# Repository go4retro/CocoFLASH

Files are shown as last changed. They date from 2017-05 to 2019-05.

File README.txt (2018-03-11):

TANDY Color Computer/Dragon FLASH ROM Cartridge

Copyright (C) 2016-18  Jim Brain, RETRO Innovations

These files are free designs; you can redistribute them and/or modify
them under the terms of the Creative Commons Attribution-ShareAlike 
4.0 International License.

You should have received a copy of the license along with this
work. If not, see <http://creativecommons.org/licenses/by-sa/4.0/>.

These files are distributed in the hope that they will be useful,
but WITHOUT ANY WARRANTY; without even the implied warranty of
MERCHANTABILITY or FITNESS FOR A PARTICULAR PURPOSE.  See the
license for more details.

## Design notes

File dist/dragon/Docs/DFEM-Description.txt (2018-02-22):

DFEM14U DESCRIPTION
===================
I have written a program to be able to use the CoCo-Flash module 
designed and built by Retroinnovations (Jim Brain) that contains 
8 Mytes of FLASH memory, 64k of SPI EEPROM and as a bonus it has a 
full compatible Orchestra 90CC double DAC incorporated.
The flash is maped to $c000-$feff (16k-256 bytes) so it can contain 
any Dragon-CoCo2 ROM we have. Moving that 'visible' window along the
FLASH contents we can store/read biggger programs (BIN or BAS files)
You will find info about that module here:
http://www.go4retro.com/products/cocoflash/

'DFEM' stands for "Dragon Flash Eeprom Manager"
The program will 'flash' programs in chunks of 16k, from $3000-6fff 
and later you could start them from the program list.
I decided to allow Binary and Basic programs besides the normal ROMs, 
so I added some code to copy those programs to RAM and execute/run them.
These loaders are part of the Program Manager, so there is no need to
add them at the beginning of the programs we want to store in Flash.

To make it easy for the user, the module should contain a customized version 
of my DosPlus5.0 extended (DP50E from now on) on bank zero. We will flash
it here if it isn't yet there.
This DP50E will copy some code into RAM and start it. The copied code will 
switch the bank on the flash module so that it can copy the Program Manager 
and in turn, start it.
The only thing that the user has to do is press the module button that 
prevents the ROM from autostarting. The DOS must be called by the Basic
after it has initialized the Dragon. If you don't press that button, the 
Dragon will simply hang :-(

I have used the SPI EEPROM included in the module as a database where the 
relevant data for each program is stored. The idea was given to me by Jim Brain. 
The programs are always shown in alpha order. Basically the EEPROM contains 
records that point to the next one, so it is a simple linked list.

To get an idea about the capacity of that module, let's  assume that all
programs (Binaries/Basic/Rom) will have a mean length of 16k, then as it
has 8 Mbytes, we could add (8Mb/16k) -> 500 programs, but if they are smaller
then we could add a lot more. 
The limit imposed by the EEPROM database is 1600 entries, so it seems that
we will not have problems for that reason.

I have created two tables in the EEPROM to help work with these entries
- One that contains 26 Categories that can be assigned to the programs
- Another for HotKeys that admits 26 entries too.
The Category can be shared by many programs, but the HotKey will point to 
only one program.

How to configure the Flash module to work on the Dragon
=======================================================
Most probably the flash will arrive to you with software for the CoCo, so we need to erase it.
The procedure we shoud apply, using some tools I included in the pack, is this
1) We CLOADM"FERASALL.WAV" or DWLOAD"FERASALL.BIN", it will ask you for the slot number where 
   the Flash module is, you can answer 0 (for no MPI) or 1-2-3-4
   Once selected, the chip will be fully erased. Don't worry if it lasts some time. The program
   sends only one command to the chip but it takes long to do the task.
2) We need to flash the Program Manager, I call it DFEM (Dragon Flash Eeprom Manager), we will
   use CLOADM"F16KFM.WAV" or DWLOAD"F16KFM.BIN", again it will ask where the module is.
3) Finally we will flash a customized version of the DP50E that will start the DFEM, for this step 
   we CLOADM"F16KDP.WAV" or DWLOAD"F16KDP.BIN"

From this moment, we may start/restart the Dragon/Tano while pressing the button on the flash module.
The Basic will call the DP50E and this will exec the DFEM so the main menu will be displayed.
On entering the program, it verifies if the EEPROM database exists, and if it is not yet created,
it will create/format the EEPROM as needed.

Possible Hardware Setups
========================
Apart from our Dragon and the Flash Module, we need some way to access/load program files to RAM
from some external hardware in oder to flash them into the module with the DFEM

These are the choices I have tested
-  A drivewire serial to USB converter, conected to a PC/Mac where we are runnuing a Drivewire server 
   (or any small Arduino/R-Pi that does the same). This is my preferred setup!
   By the way, here you can see one adapter for that setup
   http://tormod.me/products.html

-  A Tandy Multi-Pack (MPI) or a mini-MPI, together with a CoCo-SDC
   This one has the advantage of enabling us to use the Orchestra 90CC from the flash module and 
   access the score-disks from the CoCo-SDC, despite the procedure is a bit tricky. 
   I explain it at the end of this document 

Someone could also try to replace the CoCo-SDC in this last setup with a drive controller
but this has not been tested by me.

Pack Contents
=============
In the attached zip you should find:

DFEM14U.VDK that contains some utilities for the real CoCo-Flash module and a Test version
of the program. This is only of use if you have Drivewire ot the MPI and the CoCo-SDC.

All of the binary files are included as individual files in BIN format for DW use
and in WAV format for tape/Audacity use
The programs/utilities are:
DFEM14UT - The Test Version of the Program (works fine on XRoar and on any Dragon)
F16KDP   - Flashes into module the customized version of DP50E
F16KFM   - Flashes into module the Flasher Manager Program (DFEM)
EREADTAB - Shows structured Eeprom contents: LowReg, Records and Tables
FERASALL - Erases the whole FLASH chip (8Mbytes)
FERASEC  - Erases one FLASH sector (value needs to be POKED $4007-4008)
FREADALL - Shows Flashed data (shows 128 of every 256 bytes sector)
SWMAP1   - This program copies ROM to RAM and stays in MAP1 (all RAM)
TEST     - a bas file to start the Test version (ONLY in the VDK)

And two Java utility programs
Addresses  this one will create an output text file with the addresses of all the programs
           (binary or Basic) that are in the folder selected by the user. Loops untill you
           press on Cancel (to allow for another subdirectory)
MakeROM	   Selecting a folder with some programs, will create the ROM chunks needed (1 or 2)
	   will add -R1, -R2 to these parts.

FOR TEST VERSION ONLY
=====================
You can practice with the Test version, it has space reserved for *ONLY* 32 entries.
On XRoar or on a SDC you can run the program TEST.BAS to strat it
On Drivewire you simply DWLOAD"DFEM14UT.BIN"

You should know that the info you'll enter will *NOT* be saved on exit, it is just for 
practicing purposes! It simply 'emulates' the EEPROM into RAM, not the FLASH of course.
Anyway, if you want to keep the entered data to use it later, then you could do this
- Exit the program pressing the '3' key on the main menu 
- SAVE"MYDATA",&H2ea8,&H36e2,&H2ea8 or alternatively CSAVEM"MYDATA",&H2ea8,&H36e2,&H2ea8
- Later, to re-use it after starting the TEST program, just press '3' to Quit and
  LOAD"MYDATA"  or CLOADM"MYDATA"
- EXEC&H1400 and you will work with your last saved data
To be able to save to disk (VDK files), you will need to access a drivewire server
and use the DP50E functions to mount the desired disk
*** DO NOT USE THESE TRICK WITH THE REAL VERSION, IT USES THE EEPROM INSTEAD ***

HOW TO PLAY ORCHESTRA 90CC SCORES FROM THE COCO-SDC
===================================================
- Set the MPI to the slot where the Flash is
- Start the Dragon/Tano while pressing the button on the module
- Exit the program with '3'
- DWLOAD"SWMAP1.BIN" so that the DP50E gets copied into RAM
- SDRIVE1,"MUSICA" ... assuming that MUSICA is a folder where we have 10 VDK
  with ORC90 scores. This changes to slot# where the SDC is
  If you don't remember, you can use SDIR to find it out
- SLOTN4 to set the MPI switch back to slot#4 in my case. Use the number
  1-2-3-4 where you have the Flash module
- POKE&HFFDE,0 to switch to MAP0 because programs reside in ROM (Flash)
- EXEC&H1400 to enter the DFEM
- '1' to go to Program Management
- Search for the Orchestra90cc and press 'S' to start it
- Shift-Enter (recommended to be able to play at double speed)
- Now we need to change 'internally' to the slot where the SDC is
  in my case is slot #1, so I enter command '0' and enter in Orchestra
  The change slot commands are 0-1-2-3 (pressing H will show help screen)
- Now you can work with Orchestra using the contents of the selected disk
  in drive 1. Remember that pressing the button on the SDC changes to the 
  next numbered disk in that folder (only drive 1)
  As I want to listen to all of the scores I do enter
- Y * (and shift enter)
You can connect the stereo audio jack output on the Flash module to any 
amplifier to listen to the music. Enjoy!

Epilogue
========
Well, now we can say ....
Another CoCo add-on that can be used on our Dragon/Tano
I hope you enjoy your Coco-Flash module!

cheers
pere

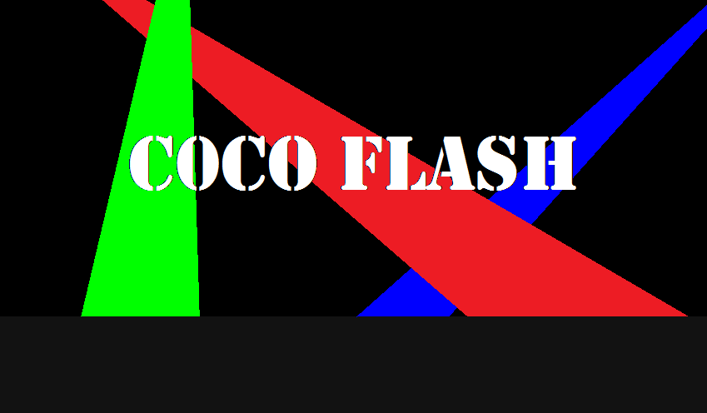
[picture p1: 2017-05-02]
doc/Coco Flash Cartridge Label.png

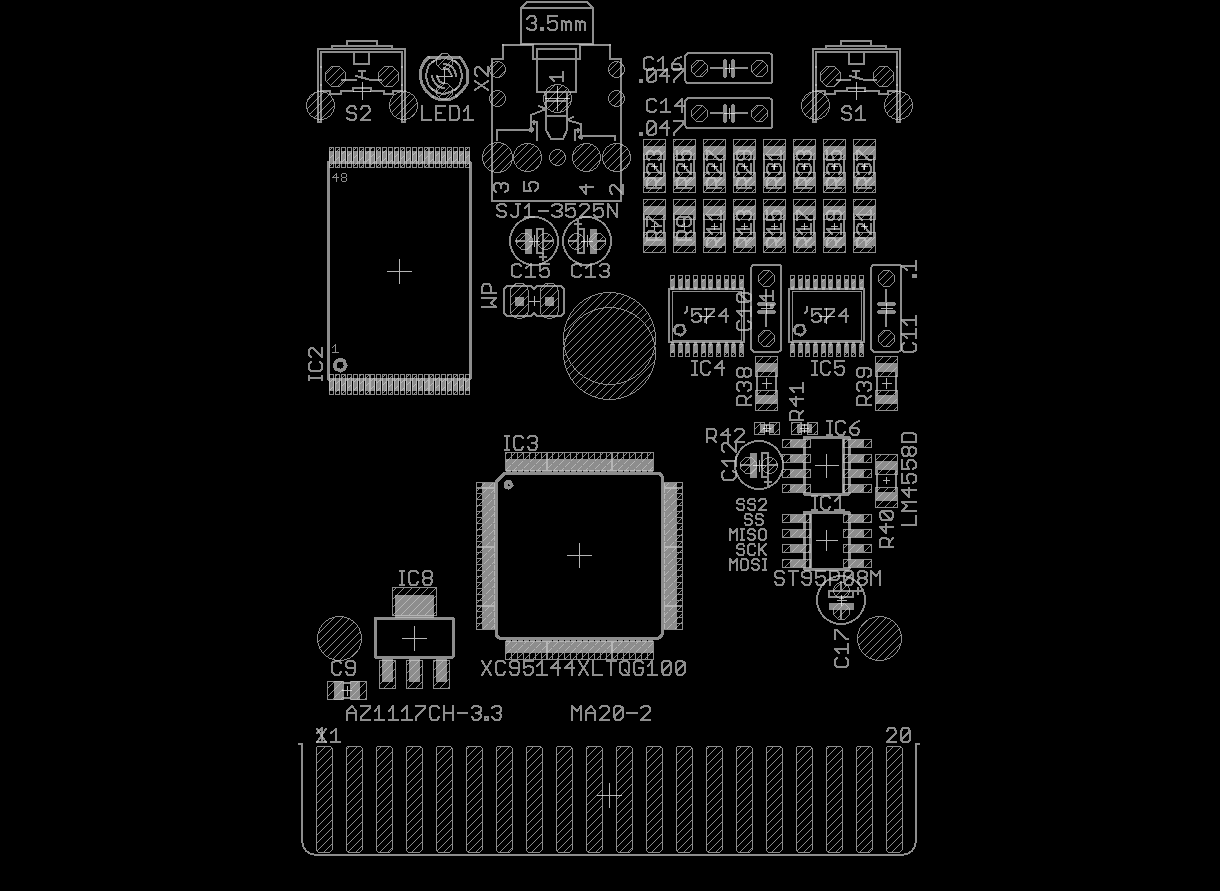
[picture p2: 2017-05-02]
pcb/tplace.png

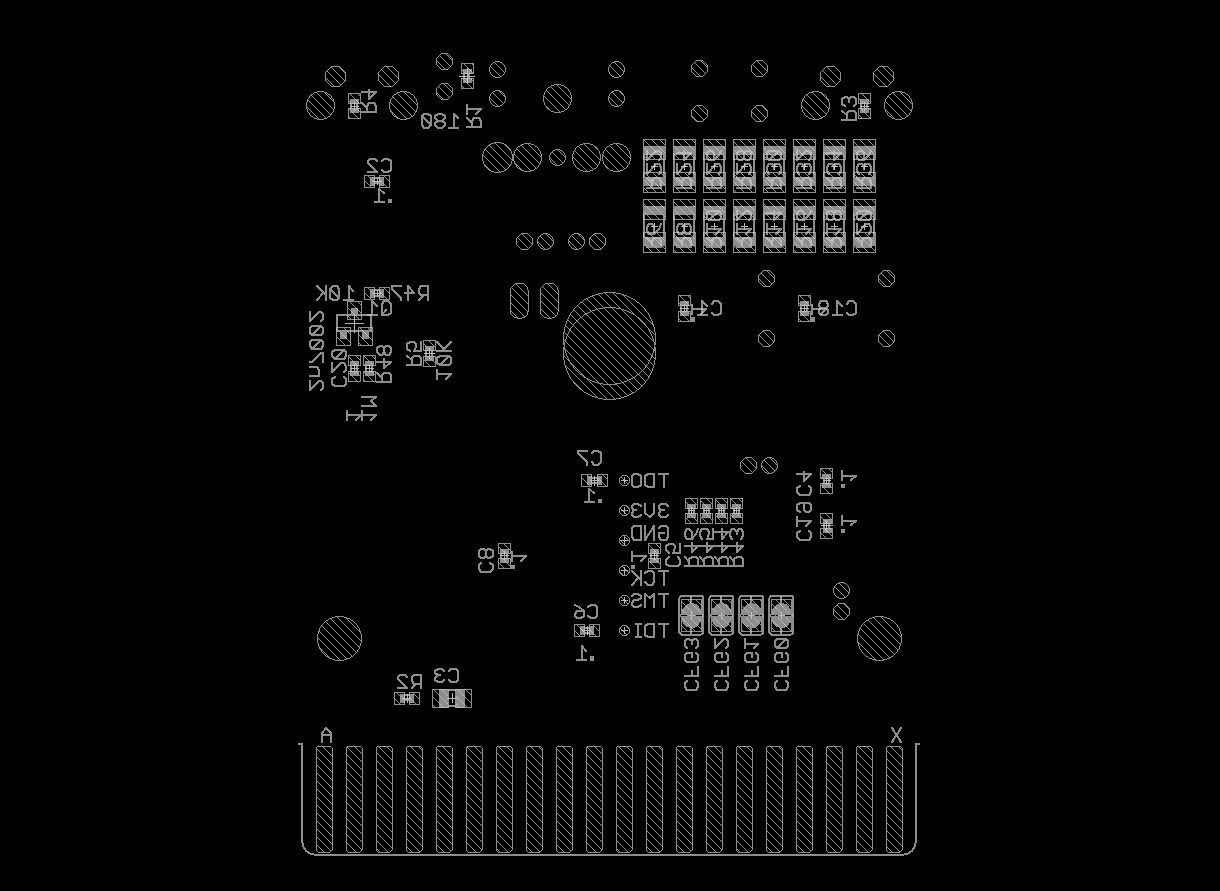
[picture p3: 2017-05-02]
pcb/bplace.png

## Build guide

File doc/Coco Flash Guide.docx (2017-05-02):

Retro Innovations

Coco Flash User Guide

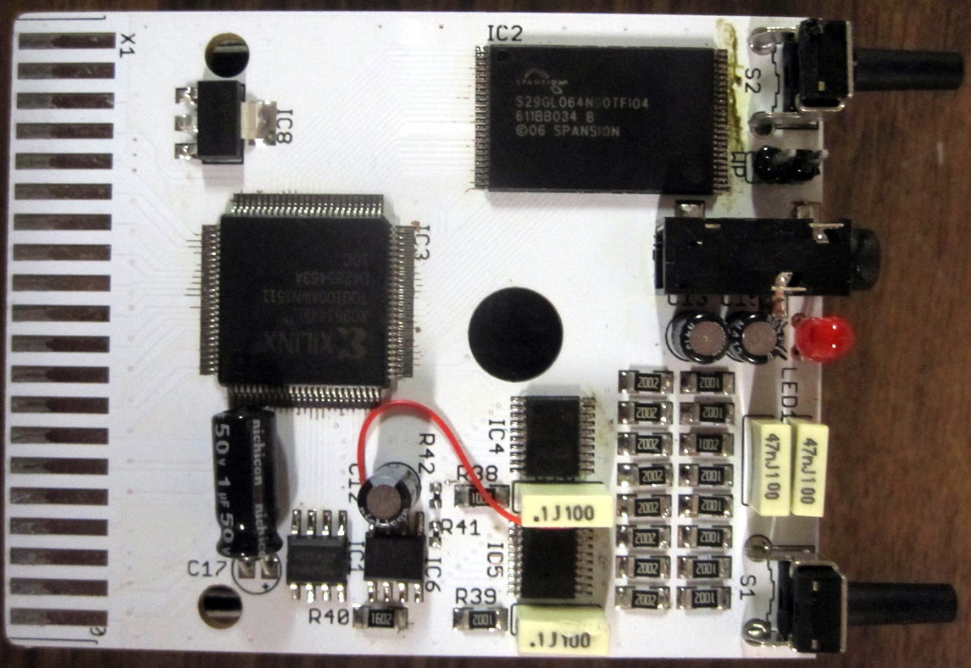
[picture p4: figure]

Retro Innovations

# CoCo Flash User Guide

Table of Contents

Description of the CoCo Flash Cartridge

This section describes what the capabilities of the CoCo Flash are and how it can be used.

t

he CoCo Flash is a programmable flash ROM cartridge. This cartridge can be used to store multiple game and DOS cartridge ROMs which can then be selected from the menu to be used. The Coco Flash can contain up to 2,048 4k ROMs at once. The sizes of these ROMs can range from 2k to 256k. Banked ROMs larger than 32k games such as Robo Cop and Predator are supported. 32k ROMs are capable of being installed by either banking or the CoCo 3 only method of mapping a full 32k ROM. The CoCo Flash is capable of being used as an Orchestra90 sound cartridge and is fully compatible with the original Orchestra 90 Cartridge, which was manufactured by Radio Shack. The CoCo Flash includes a user customizable menu which is written in BASIC. This allows the menu to be edited to list your own choice of ROMs. The CoCo Flash is also pre-loaded with 5 ROMs. The Coco Flash has a copy of HDBDOS, which is configured to auto detect a CoCo 1/2 or CoCo 3 and is configured to use a DriveWire server. The Orchestra 90 ROM is pre-loaded into the CoCo Flash as well. The CoCo Flash also contains the games “Doodle Bug”, “Buzzard Bait”, and “Temple of ROM”.

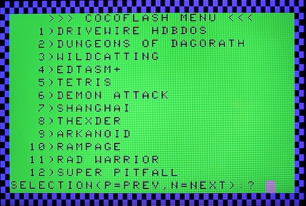
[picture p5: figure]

# How to Customize The CoCo Flash Menu

The CoCo Flash Menu is written in basic. The menu is customizable to users by loading the menu through the command:

LOAD "MENU.BAS"

After you have done this you can edit data statements from lines 10000 - 10998 to add your program info into the menu. The info you add for your program will be in this format:

"NAME OF PROGRAM",bank#,type#

- NAME OF PROGRAM represents the title or name of the added program as it will appear on the menu screen.
- bank# represents the first bank number used for the program you are adding. If you are adding a 32k program the number should be the first bank being used in the second chunk of 16k.
- type# represents the type of program you are adding. The three common options that can be used are 2, 0, and 34. The number 2 means that a game program which uses the IRQ to start is being added to the menu. If 0 has been entered then a DOS program has most likely been added. DOS programs have DK in the first two bytes of the ROM image. When the color computer starts it checks the cartridge rom memory location to see if the first two characters are DK and if they are it launches the contents of the cartridge as a basic DOS extension which adds commands to basic. Lastly, if the value is 34 then the cartridge has been split into multiple 16k cartridges. In other words, programs that are 128k, 64k, or some 32k cartridges use the 34 value since the largest CoCo ROM bank on a CoCo 1 or 2 that can be used is 16k at a time.

Once you have finished adding the entry to the menu, save the program using the command:

SAVE "MENU.BAS"

Now, because this is a basic program and ROMs only allow machine code programs to be stored in them, you must convert the basic program to machine code. Fortunately, the menu program has a routine built into it to do this. To convert the menu to machine code use the command:

RUN 60000

This will create a file named “BASROM.BIN” that can be programmed into bank 0 of the CoCo Flash. Please note that banks 0 and 1 are both reserved for the menu. The next section will discuss how to program files into the CoCo Flash.

NOTE: when programming “BASROM.BIN” the programming software will warn you that you will be overwriting bank 0 and ask you if you are sure you want to erase banks 0 and 1, type yes for the programming to continue.

# Programming the CoCo Flash

When programming the CoCo Flash in a system using a Multi-Pak interface, you should insert the CoCo Flash into slot 1 and if you are using a floppy controller or CoCo SDC, that should be inserted into slot 4 of the Multi-Pak interface. If you do not have a Multi-Pak, you may use the built in HDBDOS with DriveWire to access the programming software. To program in a new ROM into the CoCo Flash, use the command:

RUN "PRGFLASH.BAS"

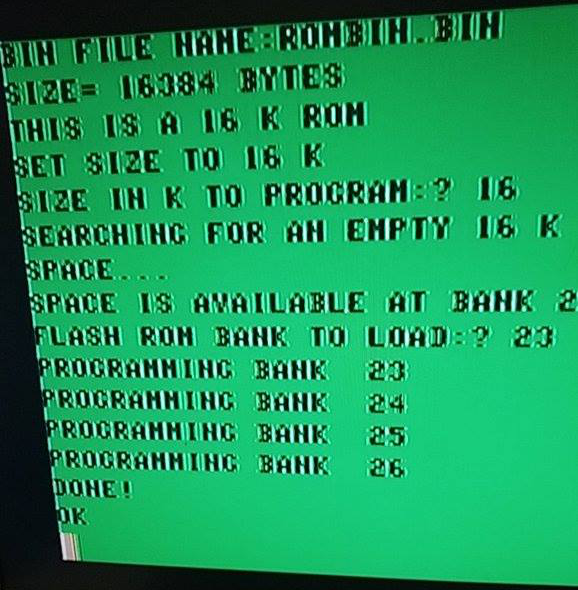
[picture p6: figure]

The first thing the program will ask for is the name of the ROM image you are trying to add to the CoCo Flash. This image must be a .bin file that loads at hex address &H4000. If the file is not in this format it must be converted. This will be discussed in the next section. The next thing the program will do is show the size of the ROM in bytes, after doing this it will calculate what the size of the ROM is in kilobytes and ask you what the size in kilobytes to program. The program will then search for an empty space the size you entered. The bank in which the space is available will be displayed and you will then be asked where you wish to load the ROM. Normally you will enter the number that that is displayed. However, there are a few exceptions to this. If you are rewriting the menu then you will want to enter 0. Another exception is if you are overwriting an existing ROM then you might want to enter the value that was used before. Once a bank value has been entered the program will proceed to program the ROM into the declared bank and if the ROM is larger than 4 k it will use the next few banks as well. For example, a 16k ROM will take 4 banks to program.

If you are using a Multi-Pak interface, after the programming completes you should type the command below:

POKE &HFF7F,&H33

This will reactivate the disk controller (or CoCo SDC) in slot 4.

# ROM to BIN Conversions

As we have mentioned previously in order to program a ROM imagse into the CoCo Flash it needs to be a .bin file with a starting address of &H4000. Most ROMs won’t be in this format so you will have to convert them. You may also have the issue of how to get the .bin file onto a disk image a color computer can read. Please note that if your ROM image is larger than 16k then you need to split it into 16k or smaller chunks. To split your file run this command:

RUN "SPLIT.BAS"

This will prompt you for the given file to split when run. Each new chunk that results from a split has a unique extension to the new file. The first unique extension is 000, then 001, then 002 and so on. If the original file is a 32k .ccc file then you will need to program the 001 file before the 000 file.

The next step is to convert the raw files into a bin so that the Coco 3 can load the file. To do this run this:

RUN "CONV2BIN.BAS"

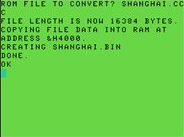
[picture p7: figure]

This will convert your file into a .bin. Once this is done you should pay attention to the newly made .bin file. This is because all the split files will have the same names once they have been converted. This will cause the new .bin file to overwrite the last file if you are converting a split file. There are two good ways to make sure each section of the split file is programed into the CoCo Flash. The first option is to program the file immediately after it has been converted and then to overwrite the file with the next split file. The other option is to rename the file so that it is not overwritten.

# CoCo Flash bank organization

When you overwrite a bank other banks will be erased. The table below shows how the banks are organized and which banks would be erased. All the banks in the same sector or essay address will be erased when any bank in that sector is overwritten. Note that you can safely write to any empty bank that does not have any data in it without affecting any other banks. For example, if banks 12, 21 and 22 have data in them and you write to bank 12 banks 21 and 22 as well all other banks in sector 8 will be erased. However, if banks 21 and 22 have data, but bank 12 is empty, you can write to bank 12 safely. In other words, you can always write to an empty bank.

Bank sector sector size | Bank sector sector size | Bank sector sector size
2044 SA0 8k 2045 SA0 8k 2046 SA1 8k 2047 SA1 8k 0 SA2 8k 1 SA2 8k 2 SA3 8k 3 SA3 8k 4 SA4 8k 5 SA4 8k 6 SA5 8k 7 SA5 8k 8 SA6 8k 9 SA6 8k 10 SA7 8k 11 SA7 8k | 12 SA8 64k 13 SA8 64k 14 SA8 64k 15 SA8 64k 16 SA8 64k 17 SA8 64k 18 SA8 64k 19 SA8 64k 20 SA8 64k 21 SA8 64k 22 SA8 64k 23 SA8 64k 24 SA8 64k 25 SA8 64k 26 SA8 64k 27 SA8 64k | ~ pattern repeats ~ 2028 SA134 64k 2029 SA134 64k 2030 SA134 64k 2031 SA134 64k 2032 SA134 64k 2033 SA134 64k 2034 SA134 64k 2035 SA134 64k 2036 SA134 64k 2037 SA134 64k 2038 SA134 64k 2039 SA134 64k 2040 SA134 64k 2041 SA134 64k 2042 SA134 64k 2043 SA134 64k

# CoCo Flash Buttons

There are two buttons on the CoCo Flash cartridge. These buttons are used for disabling cartridge auto-start which stops the menu from automatically starting on the CoCo Flash cartridge and performing a full reset which forces the cartridge back to default settings and returns you to the main menu. Disabling auto-start can be useful to prevent the Color Computer from crashing if bank 0 of the CoCo Flash becomes corrupt or invalid. The button closer to the audio jack is the reset to default button and the button closer to the led is the disable auto-start button.

# Technical Details

Coco FLASH places an 8 megabyte FLASH ROM into the Color Computer address space at $8000-$ffef. Since the entire 8MB ROM cannot be mapped into the limited address space of the CoCo, a “banking” system is utilized, where the ROM location $8000 (as seen by the Color Computer) can be moved to any 4kB boundary of the FLASH ROM. Additionally, to support multi-bank cartridges like RoboCop, which used a 16kB “offset” register to select various 16kB “pages” of ROM, Coco FLASH emulates this register as well.

Thus, to determine the actual FLASH ROM location that resides in the Coco memory map, one can utilize the following formula:

FLASH ROM location = CoCo Memory Location – $8000 + (bank * 4096) + (page * 16384).

### Coco FLASH Registers

To configure Coco FLASH, the unit provides 4 re-locatable registers at $ff64-$ff67. The registers are described as follows:

Address | Name | Function
| | Bit | Write | Read
$ff64 | CONFIG | 7 | Enable FLASH Write at $c000 (1 = enabled) | X
| | 6 | Read Bank or Device ID (1 = Device ID visible) | X
| | 5 | Enable offset register (1 = enabled) (Note 1) | X
| | 4 | Force single reset (1 = selected) | X
| | 3:2 | Select SPI source - 00 = none - 01 = EEPROM - 10 = Secondary SPI channel - 11 = Third SPI channel (not currently implemented) | X
| | 1 | Autostart (1 = on) | Left switch (1 = pressed)
| | 0 | LED (1 = on) | Right switch (1 = pressed)
$ff65 | BANK_LO | 7:0 | bits 7:0 of bank register | bits 7:0 of bank register or Device ID
| | | | 0 or Device Version
$ff66 | BANK_HI | 7:4 | 0 | bits 10:8 of bank register or CONFIG jumper values
| | 3:0 | bits 10:8 of bank register (bit 3 is 0) | SPI data in (Note 2)
$ff67 | SPI | 7:0 | SPI data out

Notes:

1. If the offset bit is enabled, any write to locations from $ff40 to $ff5f will store a new value in the offset register, shown in Table 2.
2. The SPI subsystem operates at main CPU speed. Thus, when writing a value to the SPI data register, one must wait 8 cycles before attempting to read from the register.

Table 2: Offset Register
Address | Name | Function
| | Write | Read
$ff40-$ff5f (Note 1) | OFFSET | 16kB offset | X

Notes:

1. Any location utilized by Coco FLASH or the built-in Orchestra 90-CC will not store a new value into the offset register.

In addition, the Tandy Radio Shack Orchestra 90-CC cartridge is emulated within Coco FLASH. The cartridge defaults to a base address of $ff7a, but can be altered through software. The cartridge emulation is enabled by default, but can be disabled.

### Orchestra 90-CC Registers

The Tandy/Radio Shack Orchestra 90-CC functionality has been slightly expanded, in that reads from the 2 IO locations will return valid data, as per the following table:

Address | Bit(s) | Value
$ff7a | 7:4 | Device Family ($1)
| 3:0 | Device ID ($1)
$ff7b | 7:4 | Device Version
| 3:0 | Config Jumpers

### Cartridge Configuration Register

Both Coco FLASH and Orchestra 90-CC registers can be relocated under software control. To minimize conflicts and place as few constraints on the remapping system as possible, the system utilizes an unlocking mechanism and commands to reconfigure the cartridge.

To unlock the command system, one must send a special sequence of values to the command register, located at $ff80. The sequence is $55,$aa,<DEVICE_FAMILY:DEVICE_ID>. Since one cannot be sure the sequence has not already been started, it is recommended that the program read from $ff80 before sending the command sequence, which will reset the command system.

The device families and IDs are listed below:

FAMILY | ID | Device
$1 | $1 | Tandy/RS Orchestra 90-CC
$2 | $1 | Coco FLASH

Once the proper sequence is sent, a program must send a command to execute. Currently, only 1 command is supported:

Command | Value | Data Length | Data Value(s)
Set Base Address | $01 | 1 | low byte of desired base address (setting high bit will hide device from IO memory)

To ensure command functionality works correctly when the device resides in the Tandy/RS Multi-Pak Interface (MPI), the device asserts SLENB on any write access to $ff80, which ensure the MPI will deliver the requested data.

ã Leanne Nelson

CoCo Flash Device Description

Design Customization

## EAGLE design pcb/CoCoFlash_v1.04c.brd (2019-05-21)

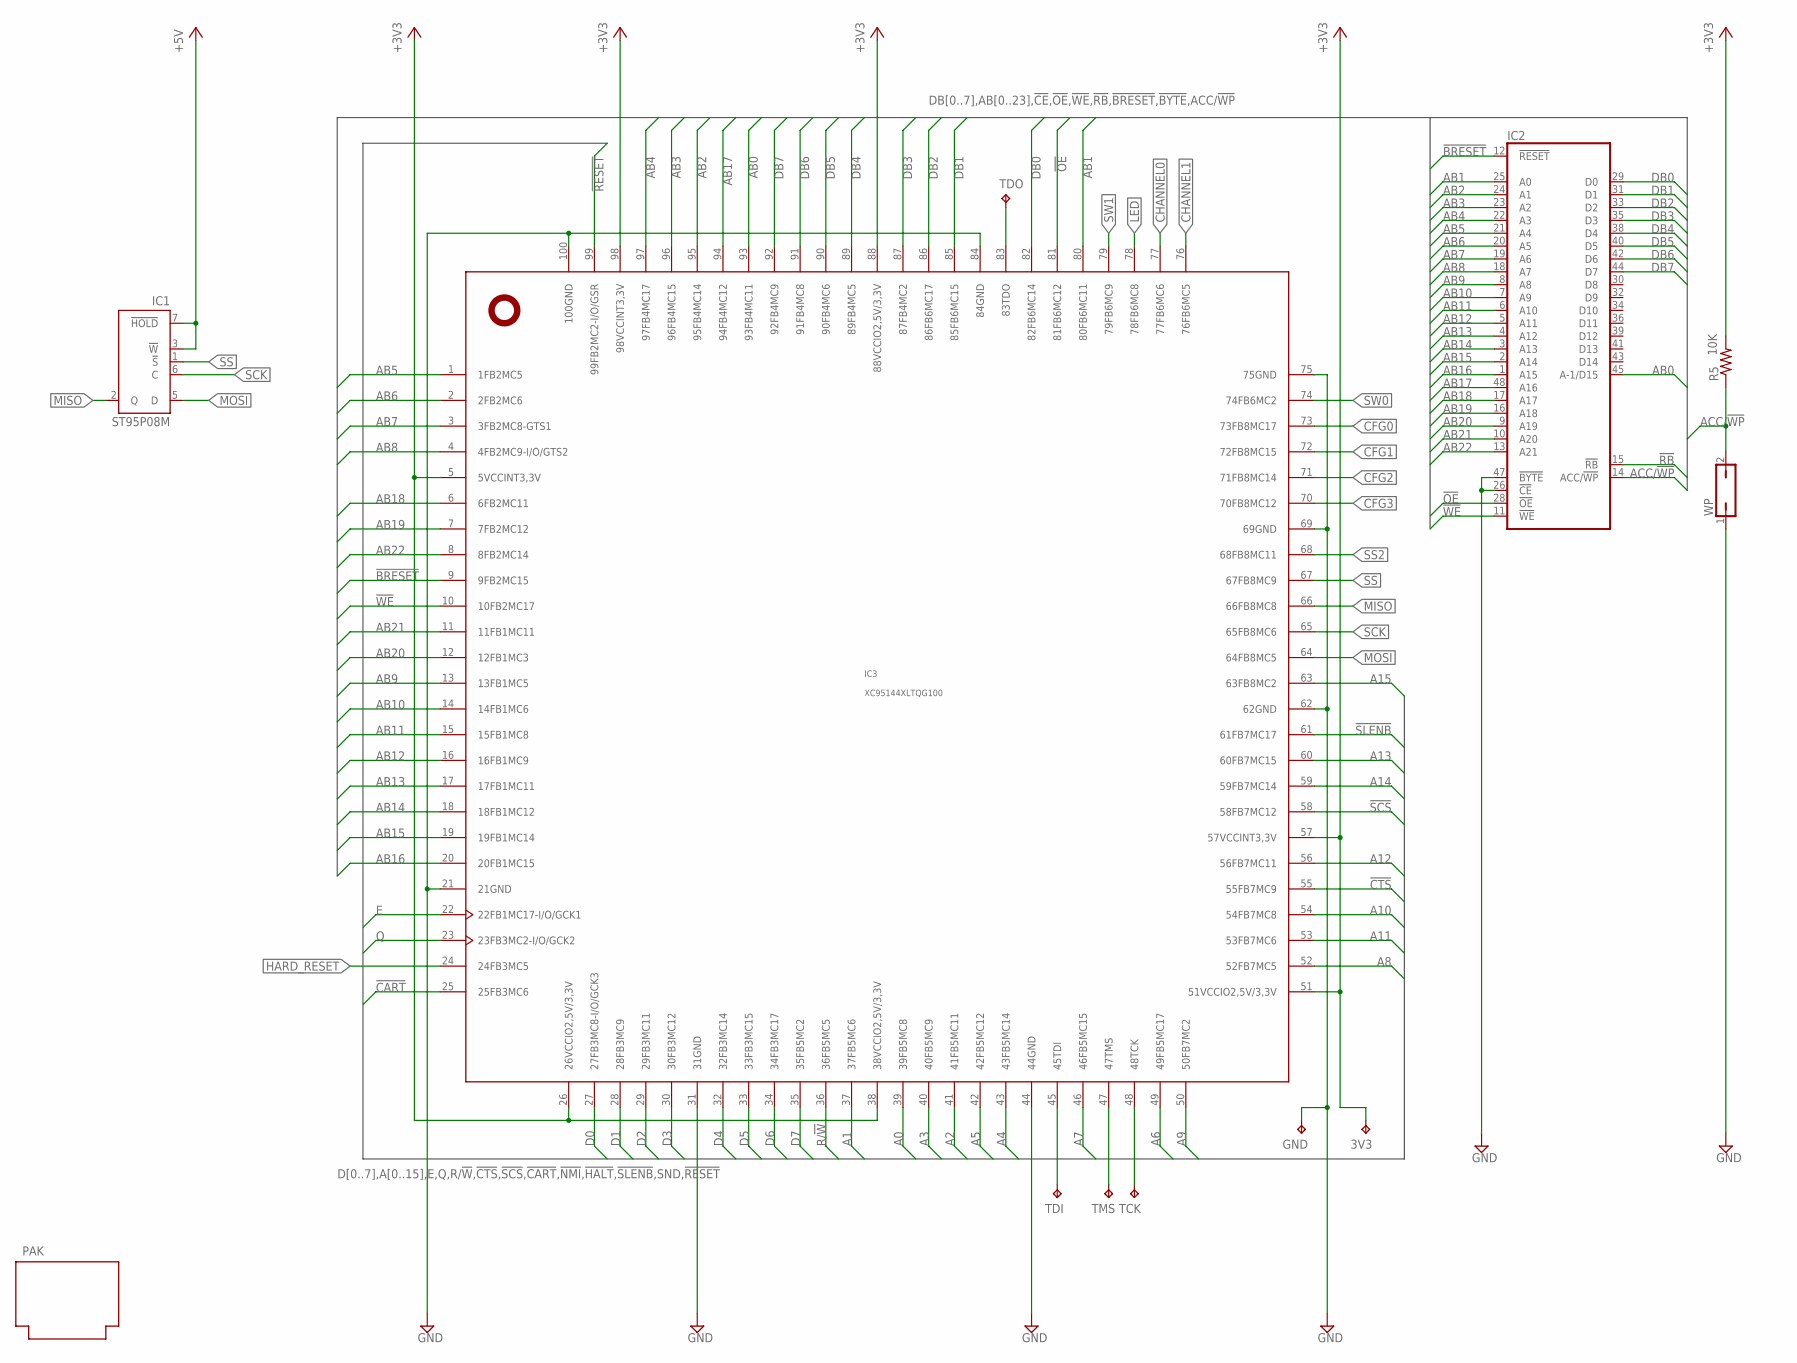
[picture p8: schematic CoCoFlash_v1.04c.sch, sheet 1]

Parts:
3V3: TPTP08R; TP08R
GND: TPTP08R; TP08R
IC1: ST95P08M; SO08
IC2: MX29LV640; TSOP48
IC3: XC95144XLTQG100; TQFP100
PAK: PROGRAM_PAK
R5: 10K; R0402
TCK: TPTP08R; TP08R
TDI: TPTP08R; TP08R
TDO: TPTP08R; TP08R
TMS: TPTP08R; TP08R
WP: JP1Q; JP1

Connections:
!BRESET: IC2.12 (!RESET), IC3.9 (9FB2MC15)
!CART: IC3.25 (25FB3MC6); also elsewhere on the board
!CTS: IC3.55 (55FB7MC9); also elsewhere on the board
!OE: IC2.28 (!OE), IC3.81 (81FB6MC12)
!RB: IC2.15 (!RB)
!RESET: IC3.99 (99FB2MC2-I/O/GSR); also elsewhere on the board
!SCS: IC3.58 (58FB7MC12); also elsewhere on the board
!SLENB: IC3.61 (61FB7MC17); also elsewhere on the board
!WE: IC2.11 (!WE), IC3.10 (10FB2MC17)
+3V3: 3V3.TP, IC3.5 (5VCCINT3,3V), IC3.26 (26VCCIO2,5V/3,3V), IC3.38 (38VCCIO2,5V/3,3V), IC3.51 (51VCCIO2,5V/3,3V), IC3.57 (57VCCINT3,3V), IC3.88 (88VCCIO2,5V/3,3V), IC3.98 (98VCCINT3,3V), R5.2; also elsewhere on the board
+5V: IC1.3 (!W), IC1.7 (!HOLD); also elsewhere on the board
A0: IC3.39 (39FB5MC8); also elsewhere on the board
A1: IC3.37 (37FB5MC6); also elsewhere on the board
A2: IC3.41 (41FB5MC11); also elsewhere on the board
A3: IC3.40 (40FB5MC9); also elsewhere on the board
A4: IC3.43 (43FB5MC14); also elsewhere on the board
A5: IC3.42 (42FB5MC12); also elsewhere on the board
A6: IC3.49 (49FB5MC17); also elsewhere on the board
A7: IC3.46 (46FB5MC15); also elsewhere on the board
A8: IC3.52 (52FB7MC5); also elsewhere on the board
A9: IC3.50 (50FB7MC2); also elsewhere on the board
A10: IC3.54 (54FB7MC8); also elsewhere on the board
A11: IC3.53 (53FB7MC6); also elsewhere on the board
A12: IC3.56 (56FB7MC11); also elsewhere on the board
A13: IC3.60 (60FB7MC15); also elsewhere on the board
A14: IC3.59 (59FB7MC14); also elsewhere on the board
A15: IC3.63 (63FB8MC2); also elsewhere on the board
AB0: IC2.45 (A-1/D15), IC3.93 (93FB4MC11)
AB1: IC2.25 (A0), IC3.80 (80FB6MC11)
AB2: IC2.24 (A1), IC3.95 (95FB4MC14)
AB3: IC2.23 (A2), IC3.96 (96FB4MC15)
AB4: IC2.22 (A3), IC3.97 (97FB4MC17)
AB5: IC2.21 (A4), IC3.1 (1FB2MC5)
AB6: IC2.20 (A5), IC3.2 (2FB2MC6)
AB7: IC2.19 (A6), IC3.3 (3FB2MC8-GTS1)
AB8: IC2.18 (A7), IC3.4 (4FB2MC9-I/O/GTS2)
AB9: IC2.8 (A8), IC3.13 (13FB1MC5)
AB10: IC2.7 (A9), IC3.14 (14FB1MC6)
AB11: IC2.6 (A10), IC3.15 (15FB1MC8)
AB12: IC2.5 (A11), IC3.16 (16FB1MC9)
AB13: IC2.4 (A12), IC3.17 (17FB1MC11)
AB14: IC2.3 (A13), IC3.18 (18FB1MC12)
AB15: IC2.2 (A14), IC3.19 (19FB1MC14)
AB16: IC2.1 (A15), IC3.20 (20FB1MC15)
AB17: IC2.48 (A16), IC3.94 (94FB4MC12)
AB18: IC2.17 (A17), IC3.6 (6FB2MC11)
AB19: IC2.16 (A18), IC3.7 (7FB2MC12)
AB20: IC2.9 (A19), IC3.12 (12FB1MC3)
AB21: IC2.10 (A20), IC3.11 (11FB1MC11)
AB22: IC2.13 (A21), IC3.8 (8FB2MC14)
ACC/!WP: IC2.14 (ACC/!WP), R5.1, WP.2
CFG0: IC3.73 (73FB8MC17); also elsewhere on the board
CFG1: IC3.72 (72FB8MC15); also elsewhere on the board
CFG2: IC3.71 (71FB8MC14); also elsewhere on the board
CFG3: IC3.70 (70FB8MC12); also elsewhere on the board
CHANNEL0: IC3.77 (77FB6MC6); also elsewhere on the board
CHANNEL1: IC3.76 (76FB6MC5); also elsewhere on the board
D0: IC3.27 (27FB3MC8-I/O/GCK3); also elsewhere on the board
D1: IC3.28 (28FB3MC9); also elsewhere on the board
D2: IC3.29 (29FB3MC11); also elsewhere on the board
D3: IC3.30 (30FB3MC12); also elsewhere on the board
D4: IC3.32 (32FB3MC14); also elsewhere on the board
D5: IC3.33 (33FB3MC15); also elsewhere on the board
D6: IC3.34 (34FB3MC17); also elsewhere on the board
D7: IC3.35 (35FB5MC2); also elsewhere on the board
DB0: IC2.29 (D0), IC3.82 (82FB6MC14)
DB1: IC2.31 (D1), IC3.85 (85FB6MC15)
DB2: IC2.33 (D2), IC3.86 (86FB6MC17)
DB3: IC2.35 (D3), IC3.87 (87FB4MC2)
DB4: IC2.38 (D4), IC3.89 (89FB4MC5)
DB5: IC2.40 (D5), IC3.90 (90FB4MC6)
DB6: IC2.42 (D6), IC3.91 (91FB4MC8)
DB7: IC2.44 (D7), IC3.92 (92FB4MC9)
E: IC3.22 (22FB1MC17-I/O/GCK1); also elsewhere on the board
GND: GND.TP, IC2.26 (!CE), IC2.47 (!BYTE), IC3.21 (21GND), IC3.31 (31GND), IC3.44 (44GND), IC3.62 (62GND), IC3.69 (69GND), IC3.75 (75GND), IC3.84 (84GND), IC3.100 (100GND), WP.1; also elsewhere on the board
HARD_RESET: IC3.24 (24FB3MC5); also elsewhere on the board
LED: IC3.78 (78FB6MC8); also elsewhere on the board
MISO: IC1.2 (Q), IC3.66 (66FB8MC8)
MOSI: IC1.5 (D), IC3.64 (64FB8MC5)
unnamed: IC3.45 (45TDI), TDI.TP
unnamed: IC3.47 (47TMS), TMS.TP
unnamed: IC3.48 (48TCK), TCK.TP
unnamed: IC3.83 (83TDO), TDO.TP
Q: IC3.23 (23FB3MC2-I/O/GCK2); also elsewhere on the board
R/!W: IC3.36 (36FB5MC5); also elsewhere on the board
SCK: IC1.6 (C), IC3.65 (65FB8MC6)
SS: IC1.1 (!S), IC3.67 (67FB8MC9)
SS2: IC3.68 (68FB8MC11)
SW0: IC3.74 (74FB6MC2); also elsewhere on the board
SW1: IC3.79 (79FB6MC9); also elsewhere on the board

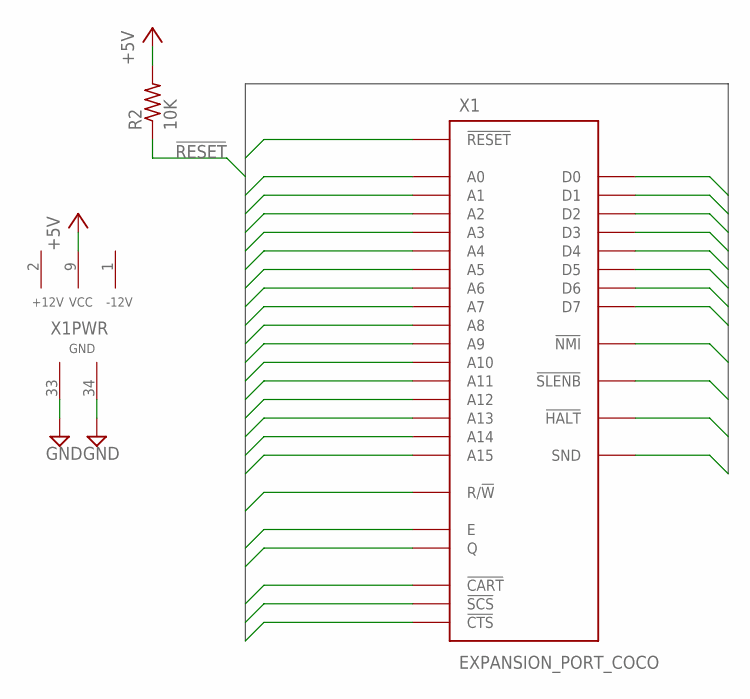
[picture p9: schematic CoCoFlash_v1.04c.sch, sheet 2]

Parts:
R2: 10K; R0402
X1: EXPANSION_PORT_COCO; MA20-2

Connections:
!CART: X1.8 (!CART); also elsewhere on the board
!CTS: X1.32 (!CTS); also elsewhere on the board
!HALT: X1.3 (!HALT)
!NMI: X1.4 (!NMI)
!RESET: R2.1, X1.5 (!RESET); also elsewhere on the board
!SCS: X1.36 (!SCS); also elsewhere on the board
!SLENB: X1.40 (!SLENB); also elsewhere on the board
+5V: R2.2, X1.9 (VCC); also elsewhere on the board
+12V: X1.2 (+12V)
-12V: X1.1 (-12V)
A0: X1.19 (A0); also elsewhere on the board
A1: X1.20 (A1); also elsewhere on the board
A2: X1.21 (A2); also elsewhere on the board
A3: X1.22 (A3); also elsewhere on the board
A4: X1.23 (A4); also elsewhere on the board
A5: X1.24 (A5); also elsewhere on the board
A6: X1.25 (A6); also elsewhere on the board
A7: X1.26 (A7); also elsewhere on the board
A8: X1.27 (A8); also elsewhere on the board
A9: X1.28 (A9); also elsewhere on the board
A10: X1.29 (A10); also elsewhere on the board
A11: X1.30 (A11); also elsewhere on the board
A12: X1.31 (A12); also elsewhere on the board
A13: X1.37 (A13); also elsewhere on the board
A14: X1.38 (A14); also elsewhere on the board
A15: X1.39 (A15); also elsewhere on the board
D0: X1.10 (D0); also elsewhere on the board
D1: X1.11 (D1); also elsewhere on the board
D2: X1.12 (D2); also elsewhere on the board
D3: X1.13 (D3); also elsewhere on the board
D4: X1.14 (D4); also elsewhere on the board
D5: X1.15 (D5); also elsewhere on the board
D6: X1.16 (D6); also elsewhere on the board
D7: X1.17 (D7); also elsewhere on the board
E: X1.6 (E); also elsewhere on the board
GND: X1.33 (GND), X1.34 (GND); also elsewhere on the board
Q: X1.7 (Q); also elsewhere on the board
R/!W: X1.18 (R/!W); also elsewhere on the board
SND: X1.35 (SND); also elsewhere on the board

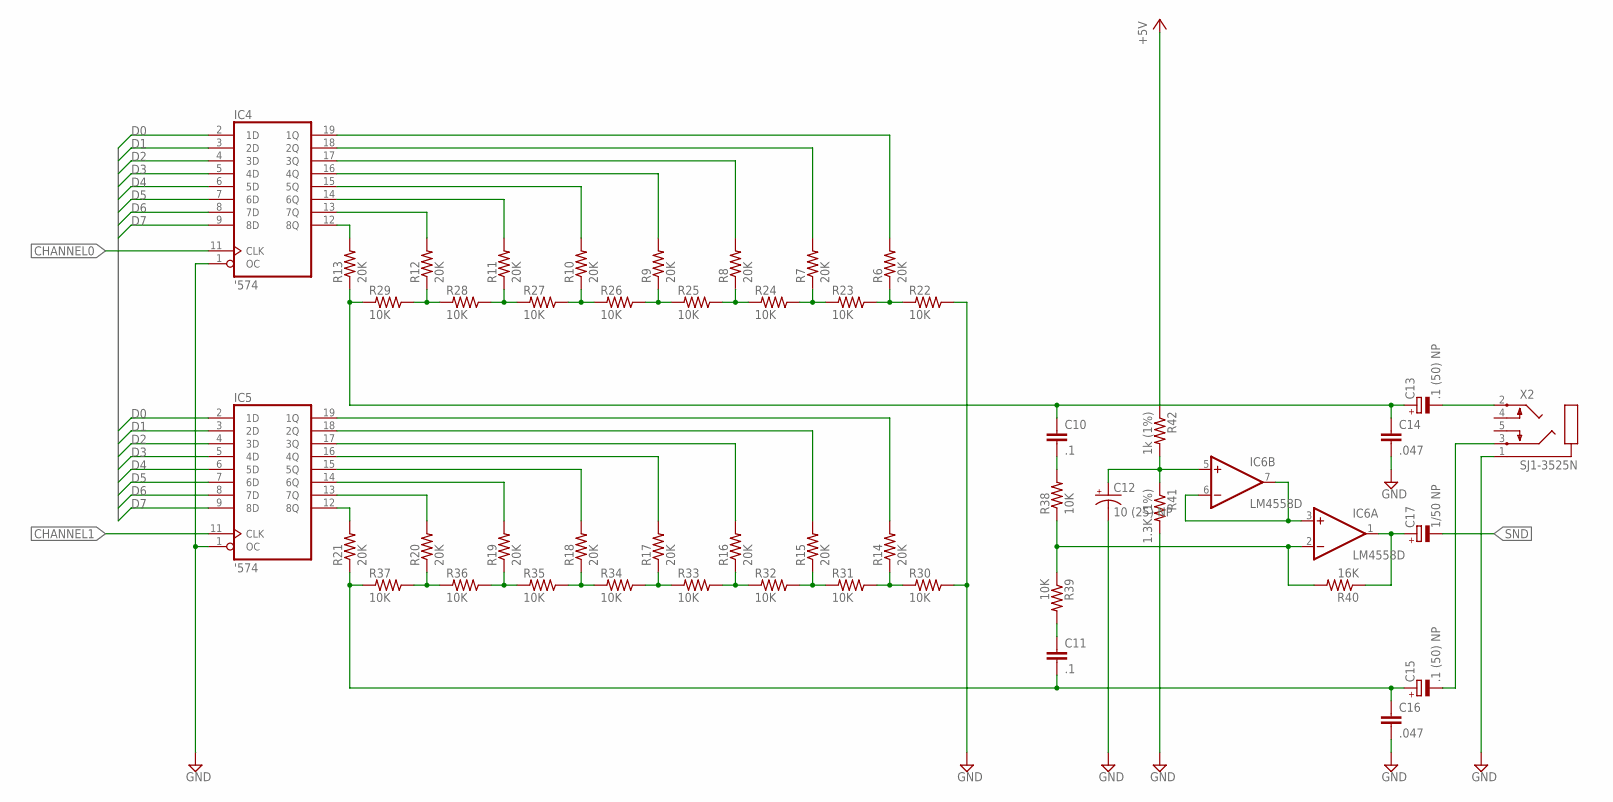
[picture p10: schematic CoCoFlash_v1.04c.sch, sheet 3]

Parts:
C10, C11: .1; C050-025X075
C12: 10 (25) NP; E1,8-4
C13, C15: .1 (50) NP; E1,8-4
C14, C16: .047; C050-025X075
C17: 1/50 NP; E1,8-4
IC4, IC5: '574; TSSOP20
IC6: LM4558D; SO08
R6, R7, R8, R9, R10, R11, R12, R13, R14, R15, R16, R17, R18, R19, R20, R21: 20K; R1206
R22, R23, R24, R25, R26, R27, R28, R29, R30, R31, R32, R33, R34, R35, R36, R37, R38, R39: 10K; R1206
R40: 16K; R1206
R41: 1.3K (1%); R0402
R42: 1k (1%); R0402
X2: SJ1-3525N

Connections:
+5V: R42.1; also elsewhere on the board
CHANNEL0: IC4.11 (CLK); also elsewhere on the board
CHANNEL1: IC5.11 (CLK); also elsewhere on the board
D0: IC4.2 (1D), IC5.2 (1D); also elsewhere on the board
D1: IC4.3 (2D), IC5.3 (2D); also elsewhere on the board
D2: IC4.4 (3D), IC5.4 (3D); also elsewhere on the board
D3: IC4.5 (4D), IC5.5 (4D); also elsewhere on the board
D4: IC4.6 (5D), IC5.6 (5D); also elsewhere on the board
D5: IC4.7 (6D), IC5.7 (6D); also elsewhere on the board
D6: IC4.8 (7D), IC5.8 (7D); also elsewhere on the board
D7: IC4.9 (8D), IC5.9 (8D); also elsewhere on the board
GND: C12.-, C14.2, C16.2, IC4.1 (OC), IC5.1 (OC), R22.1, R30.1, R41.2, X2.1; also elsewhere on the board
unnamed: IC4.18 (2Q), R7.2
unnamed: R6.1, R22.2, R23.1
unnamed: C15.-, X2.3
unnamed: IC4.19 (1Q), R6.2
unnamed: C13.-, X2.2
unnamed: IC4.17 (3Q), R8.2
unnamed: IC4.16 (4Q), R9.2
unnamed: IC4.15 (5Q), R10.2
unnamed: IC4.14 (6Q), R11.2
unnamed: IC4.13 (7Q), R12.2
unnamed: IC4.12 (8Q), R13.2
unnamed: R7.1, R23.2, R24.1
unnamed: R8.1, R24.2, R25.1
unnamed: R9.1, R25.2, R26.1
unnamed: R10.1, R26.2, R27.1
unnamed: R11.1, R27.2, R28.1
unnamed: R12.1, R28.2, R29.1
unnamed: C10.1, C13.+, C14.1, R13.1, R29.2
unnamed: IC5.19 (1Q), R14.2
unnamed: IC5.18 (2Q), R15.2
unnamed: IC5.17 (3Q), R16.2
unnamed: IC5.16 (4Q), R17.2
unnamed: IC5.15 (5Q), R18.2
unnamed: IC5.14 (6Q), R19.2
unnamed: IC5.13 (7Q), R20.2
unnamed: IC5.12 (8Q), R21.2
unnamed: C11.2, C15.+, C16.1, R21.1, R37.2
unnamed: R20.1, R36.2, R37.1
unnamed: R19.1, R35.2, R36.1
unnamed: R18.1, R34.2, R35.1
unnamed: R17.1, R33.2, R34.1
unnamed: R16.1, R32.2, R33.1
unnamed: R15.1, R31.2, R32.1
unnamed: R14.1, R30.2, R31.1
unnamed: C10.2, R38.2
unnamed: C11.1, R39.2
unnamed: IC6.2 (-IN), R38.1, R39.1, R40.2
unnamed: IC6.3 (+IN), IC6.6 (-IN), IC6.7 (OUT)
unnamed: C17.+, IC6.1 (OUT), R40.1
unnamed: C12.+, IC6.5 (+IN), R41.1, R42.2
SND: C17.-; also elsewhere on the board

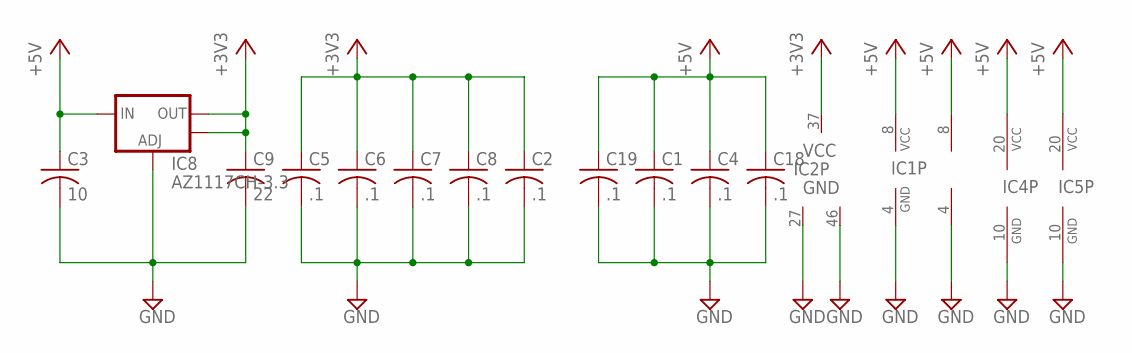
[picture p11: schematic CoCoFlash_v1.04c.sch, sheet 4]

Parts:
C1, C2, C4, C5, C6, C7, C8, C18, C19: .1; C0402
C3: 10; C0805
C9: 22; C0805
IC1: ST95P08M; SO08
IC2: MX29LV640; TSOP48
IC4, IC5: '574; TSSOP20
IC6: LM4558D; SO08
IC8: AZ1117CH-3.3; SOT223

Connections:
+3V3: C2.1, C5.1, C6.1, C7.1, C8.1, C9.1, IC2.37 (VCC), IC8.2 (OUT), IC8.4 (OUT); also elsewhere on the board
+5V: C1.1, C3.1, C4.1, C18.1, C19.1, IC1.8 (VCC), IC4.20 (VCC), IC5.20 (VCC), IC6.8 (V+), IC8.3 (IN); also elsewhere on the board
GND: C1.2, C2.2, C3.2, C4.2, C5.2, C6.2, C7.2, C8.2, C9.2, C18.2, C19.2, IC1.4 (GND), IC2.27 (GND), IC2.46 (GND), IC4.10 (GND), IC5.10 (GND), IC6.4 (V-), IC8.1 (ADJ); also elsewhere on the board

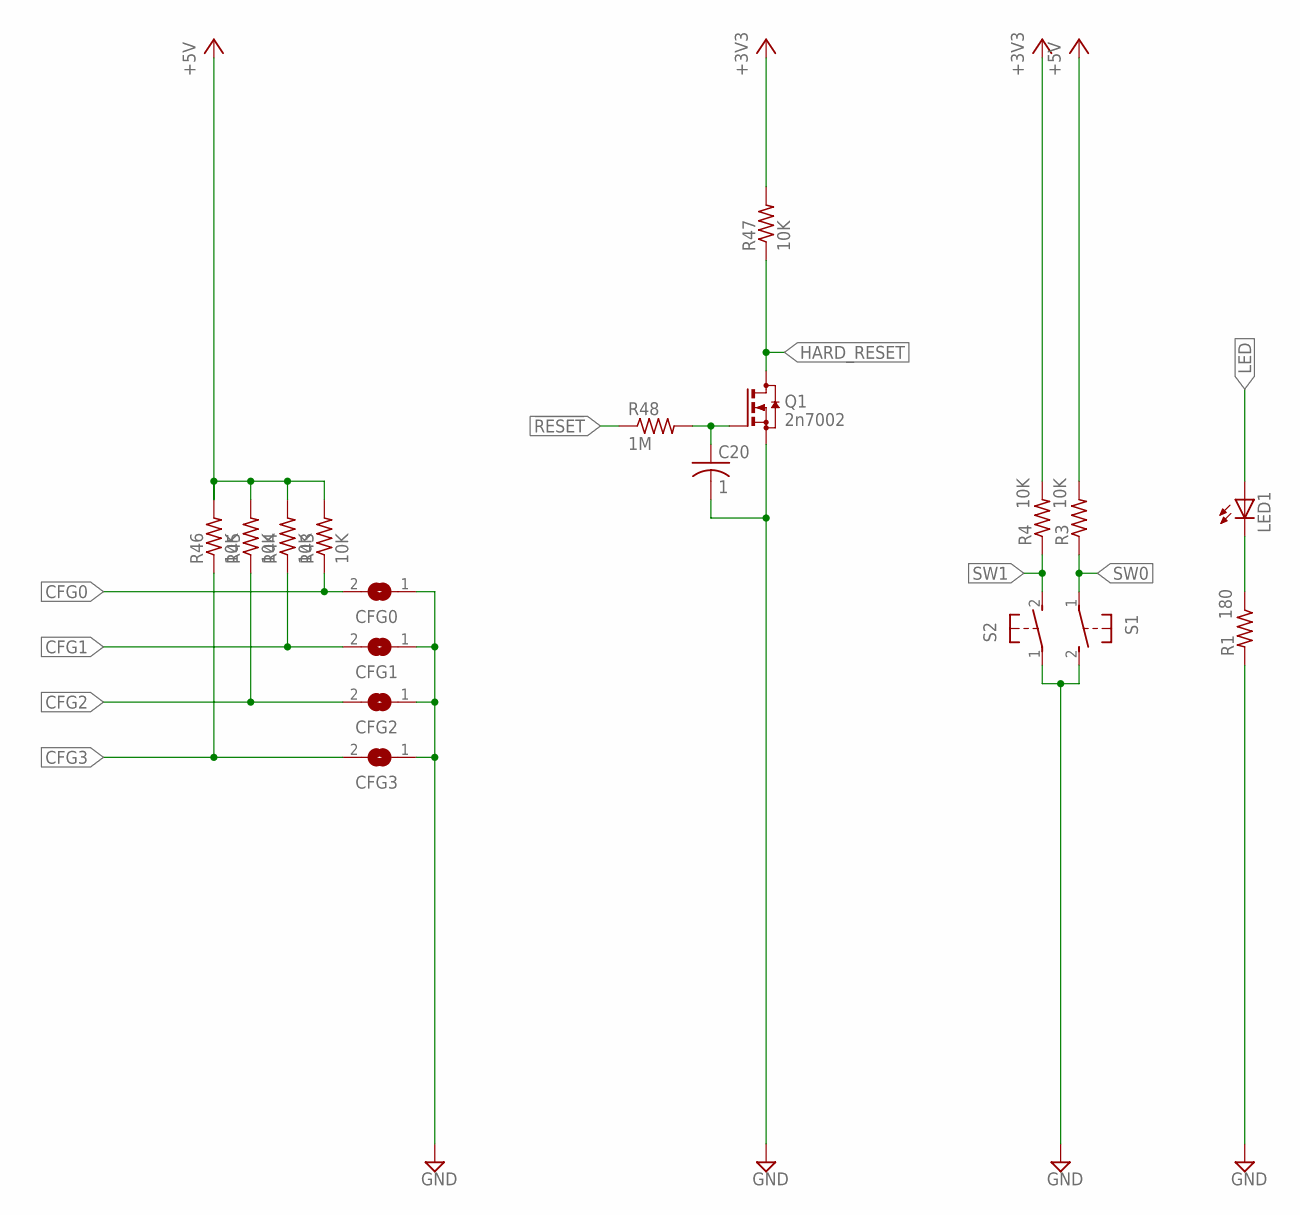
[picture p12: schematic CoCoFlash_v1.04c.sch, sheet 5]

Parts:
C20: 1; C0402
CFG0, CFG1, CFG2, CFG3: SJ
LED1: LED3MM
Q1: 2n7002; SOT23
R1: 180; R0402
R3, R4, R43, R44, R45, R46, R47: 10K; R0402
R48: 1M; R0402
S1, S2: 31-XX; B3F-31XX

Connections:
!RESET: R48.1; also elsewhere on the board
+3V1: C20.1, Q1.1 (G), R48.2
+3V3: R4.2, R47.2; also elsewhere on the board
+5V: R3.2, R43.2, R44.2, R45.2, R46.2; also elsewhere on the board
CFG0: CFG0.2, R43.1; also elsewhere on the board
CFG1: CFG1.2, R44.1; also elsewhere on the board
CFG2: CFG2.2, R45.1; also elsewhere on the board
CFG3: CFG3.2, R46.1; also elsewhere on the board
GND: C20.2, CFG0.1, CFG1.1, CFG2.1, CFG3.1, Q1.2 (S), R1.2, S1.2 (S), S2.1; also elsewhere on the board
HARD_RESET: Q1.3 (D), R47.1; also elsewhere on the board
LED: LED1.A; also elsewhere on the board
unnamed: LED1.K (C), R1.1
SW0: R3.1, S1.1; also elsewhere on the board
SW1: R4.1, S2.2 (S); also elsewhere on the board

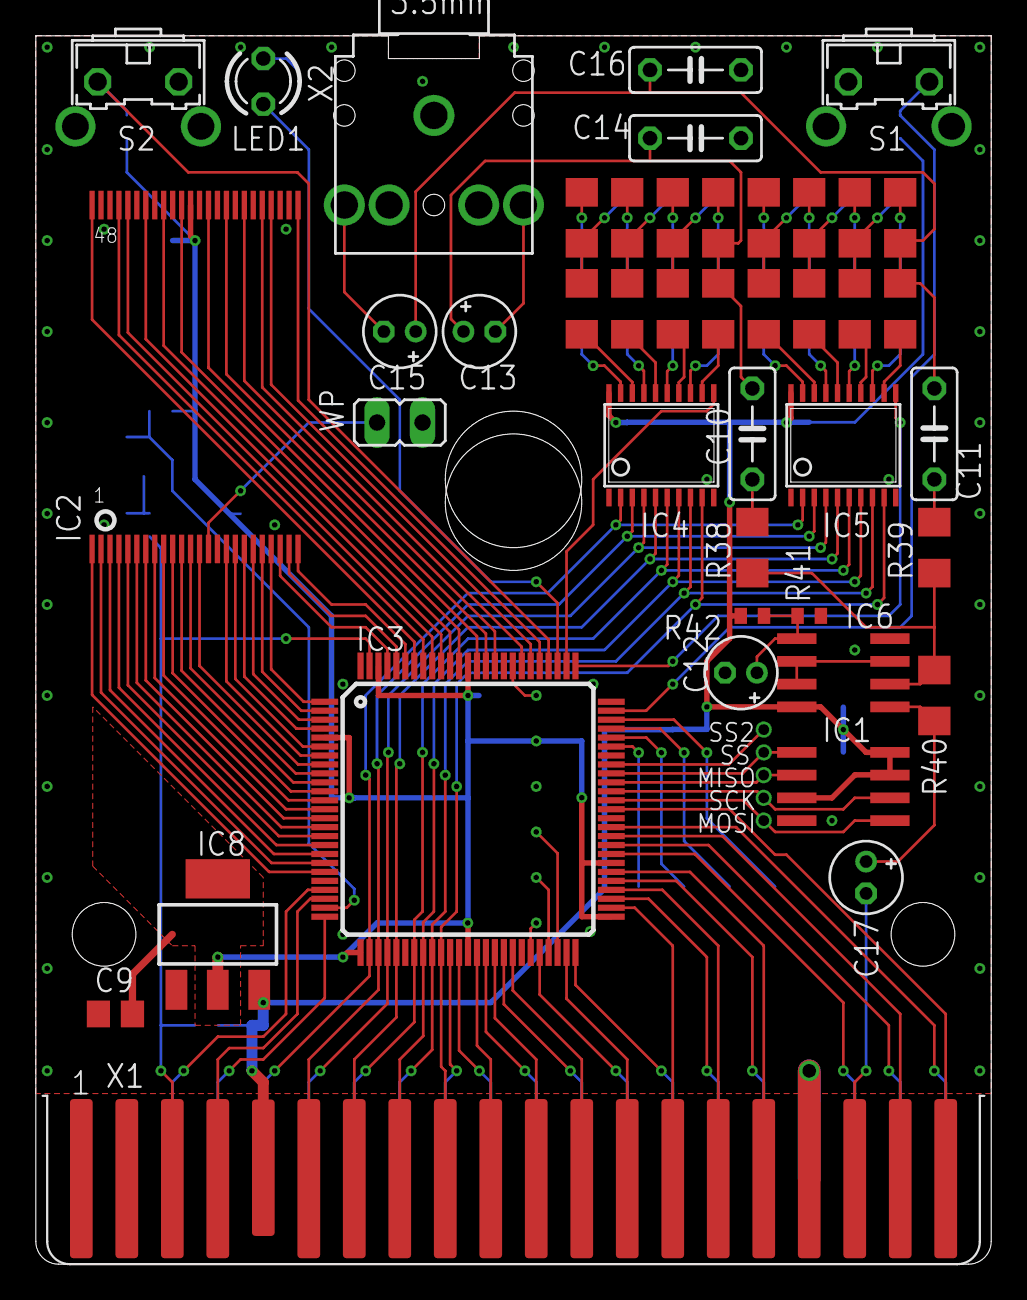
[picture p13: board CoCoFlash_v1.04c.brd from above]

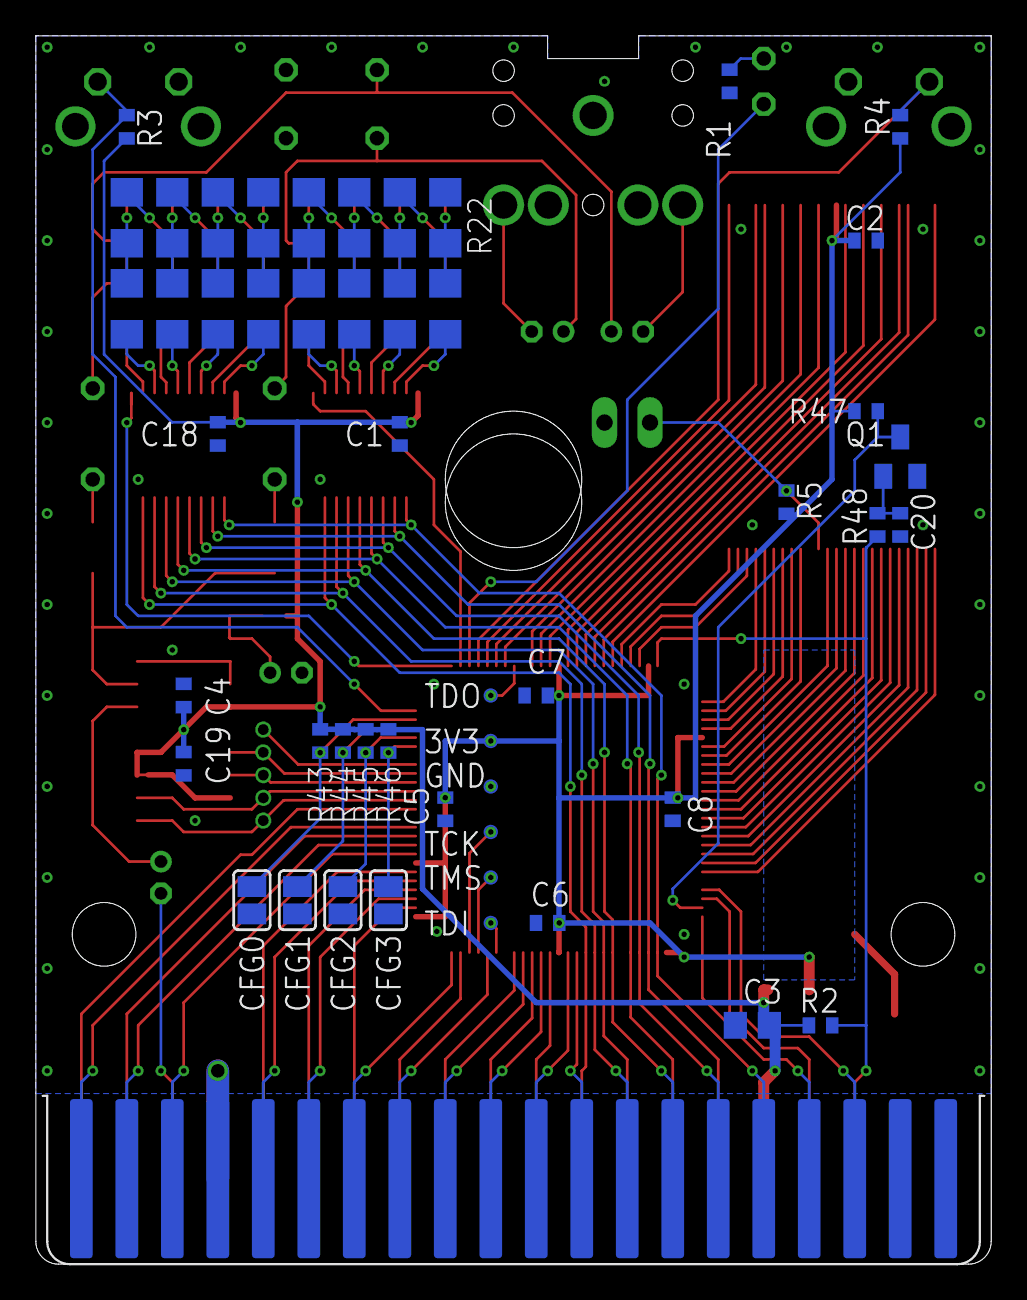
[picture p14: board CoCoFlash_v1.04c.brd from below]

Board: 2 copper layers, 53.3 x 68.6 mm, 93 parts (49 on the bottom side), 131 nets.

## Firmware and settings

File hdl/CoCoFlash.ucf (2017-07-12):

#PACE: Start of Constraints generated by PACE

#PACE: Start of PACE I/O Pin Assignments
NET "_cart"  LOC = "P25"  ; 
NET "_channel<0>"  LOC = "P76"  ;
NET "_channel<1>"  LOC = "P77"  ;
NET "_cts"  LOC = "P55"  ; 
NET "_freset"  LOC = "P9"  ; 
NET "_oe"  LOC = "P81"  ; 
NET "_reset"  LOC = "P99"  ; 
NET "_scs"  LOC = "P58"  ; 
NET "_slenb"  LOC = "P61"  ; 
NET "_ss"  LOC = "P67"  ; 
NET "_ss2"  LOC = "P68"  ; 
NET "_we"  LOC = "P10"  ; 
NET "address<0>"  LOC = "P39"  ; 
NET "address<10>"  LOC = "P54"  ; 
NET "address<11>"  LOC = "P53"  ; 
NET "address<12>"  LOC = "P56"  ; 
NET "address<13>"  LOC = "P60"  ; 
NET "address<14>"  LOC = "P59"  ; 
NET "address<15>"  LOC = "P63"  ; 
NET "address<1>"  LOC = "P37"  ; 
NET "address<2>"  LOC = "P41"  ; 
NET "address<3>"  LOC = "P40"  ; 
NET "address<4>"  LOC = "P43"  ; 
NET "address<5>"  LOC = "P42"  ; 
NET "address<6>"  LOC = "P49"  ; 
NET "address<7>"  LOC = "P46"  ; 
NET "address<8>"  LOC = "P52"  ; 
NET "address<9>"  LOC = "P50"  ; 
NET "baddress<0>"  LOC = "P93"  ; 
NET "baddress<10>"  LOC = "P14"  ; 
NET "baddress<11>"  LOC = "P15"  ; 
NET "baddress<12>"  LOC = "P16"  ; 
NET "baddress<13>"  LOC = "P17"  ; 
NET "baddress<14>"  LOC = "P18"  ; 
NET "baddress<15>"  LOC = "P19"  ; 
NET "baddress<16>"  LOC = "P20"  ; 
NET "baddress<17>"  LOC = "P94"  ; 
NET "baddress<18>"  LOC = "P6"  ; 
NET "baddress<19>"  LOC = "P7"  ; 
NET "baddress<1>"  LOC = "P80"  ; 
NET "baddress<20>"  LOC = "P12"  ; 
NET "baddress<21>"  LOC = "P11"  ; 
NET "baddress<22>"  LOC = "P8"  ; 
NET "baddress<2>"  LOC = "P95"  ; 
NET "baddress<3>"  LOC = "P96"  ; 
NET "baddress<4>"  LOC = "P97"  ; 
NET "baddress<5>"  LOC = "P1"  ; 
NET "baddress<6>"  LOC = "P2"  ; 
NET "baddress<7>"  LOC = "P3"  ; 
NET "baddress<8>"  LOC = "P4"  ; 
NET "baddress<9>"  LOC = "P13"  ; 
NET "bdata<0>"  LOC = "P82"  ; 
NET "bdata<1>"  LOC = "P85"  ; 
NET "bdata<2>"  LOC = "P86"  ; 
NET "bdata<3>"  LOC = "P87"  ; 
NET "bdata<4>"  LOC = "P89"  ; 
NET "bdata<5>"  LOC = "P90"  ; 
NET "bdata<6>"  LOC = "P91"  ; 
NET "bdata<7>"  LOC = "P92"  ; 
NET "cfg<0>"  LOC = "P73"  ; 
NET "cfg<1>"  LOC = "P72"  ; 
NET "cfg<2>"  LOC = "P71"  ; 
NET "cfg<3>"  LOC = "P70"  ; 
NET "data<0>"  LOC = "P27"  ; 
NET "data<1>"  LOC = "P28"  ; 
NET "data<2>"  LOC = "P29"  ; 
NET "data<3>"  LOC = "P30"  ; 
NET "data<4>"  LOC = "P32"  ; 
NET "data<5>"  LOC = "P33"  ; 
NET "data<6>"  LOC = "P34"  ; 
NET "data<7>"  LOC = "P35"  ; 
NET "e"  LOC = "P22"  ; 
NET "led"  LOC = "P78"  ; 
NET "miso"  LOC = "P66"  ; 
NET "mosi"  LOC = "P64"  ; 
NET "q"  LOC = "P23"  ; 
NET "r_w"  LOC = "P36"  ; 
NET "reset_long"  LOC = "P24"  ; 
NET "sck"  LOC = "P65"  ; 
NET "switch<0>"  LOC = "P74"  ; 
NET "switch<1>"  LOC = "P79"  ; 

#PACE: Start of PACE Area Constraints

#PACE: Start of PACE Prohibit Constraints

#PACE: End of Constraints generated by PACE

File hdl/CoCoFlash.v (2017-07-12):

`timescale 1ns / 1ps
/*
    CocoFLASH - TANDY Color Computer 1,2,3 8MiB FLASH ROM cartridge
                with Orchestra 90 emulation

    Copyright Jim Brain and RETRO Innovations, 2015-2016

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
    CocoFLash.v: Main functionality of flash cartridge

*/

//////////////////////////////////////////////////////////////////////////////////
// Company: RETRO Innovations
// Engineer: Jim Brain
// 
// Create Date:    21:22:56 03/27/2015 
// Design Name: CocoFLASH
// Module Name:    CoCoFlash 
// Project Name: 
// Target Devices: XC95144XL
// Tool versions: ISE 13
// Description: 
//
// Dependencies: 
//
// Revision: 
// Revision 0.01 - File Created
// Additional Comments: 
//
//////////////////////////////////////////////////////////////////////////////////

module CoCoFlash(
                 input _reset,
                 input e, 
                 input q, 
                 input r_w, 
                 input [15:0]address, 
                 inout [7:0]data, 
                 input _cts, 
                 output _cart, 
                 output [22:0]baddress, 
                 inout [7:0]bdata, 
                 output _we, 
                 output _oe, 
                 input _scs, 
                 inout _slenb, 
                 output _freset, 
                 input [1:0]switch, 
                 output led, 
                 output _ss,
                 output _ss2,
                 output sck, 
                 output mosi, 
                 input miso,
                 output [1:0]_channel,
                 input [3:0]cfg,
                 input reset_long
                );
                
parameter FAM_RS =         4'h1;  // TANDY/RS
parameter ID_OR90 =        4'h1;  // Orchestra 90
parameter VER_OR90 =       4'h2;  // second version

parameter FAM_RI =         4'h2;  // RETRO Innovations
parameter ID_CF =          4'h1;  // CocoFLASH
parameter VER_CF =         4'h1;  // first version

wire [7:0]data_reg;
wire [7:0]data_regc;
wire [7:0]data_reg_or90;
wire [7:0]data_mux;
wire [7:0]data_bank_id;
wire [7:0]data_bank_ver;
wire [10:0]data_bank;
wire [10:0]bank;
wire [2:0]state;
wire [4:0]data_base;
wire [5:0]data_base_or90;
wire reset_autostart;
reg [1:0]ctr_init;
wire clock_spi;
wire [7:0]data_spi;
wire [7:0]data_offset;

reg flag_autostart;
wire [1:0]ss;
wire led_state;
wire flag_reset;
wire flag_offset;
wire flag_id;
wire flag_pgm;
wire flag_hidden;
wire flag_hidden_or90;
wire hard_reset;

wire ce_ffxx;
wire [3:0]_cfg;

assign _cfg =              !cfg;

assign hard_reset =        (!_reset & !switch[1]) | (flag_reset ? !_reset : reset_long);
assign reset_autostart =   hard_reset | (!ctr_init[1]);

assign led =               (hard_reset ? 1 : _reset & led_state); // show hard_reset and state of led, assuming reset is not held down
assign _ss =               !(ss[1:0] == 'b01);
assign _ss2 =              !(ss[1:0] == 'b10);

assign flag_hidden =       data_base[4];
assign flag_hidden_or90 =  data_base_or90[5];

//assign clock_spi = 		  q ^ e;  // doubled clock
assign clock_spi = 			e;

assign _cart = 				(flag_autostart & !q ? 0 : 'bz);

assign ce_ffxx =           (address[15:8] == 8'hff);
assign ce_reg_base =			ce_ffxx & (address[7:0] == 8'h80);  //ff80
assign we_reg_base =			!r_w & ce_reg_base;  //ff80

//assign ce_or90 =           (ce_ffxx & (address[7:1]== 'b0111101)); //ff7a and ff7b
assign ce_or90 =           (
                            !flag_hidden_or90                  // we're not hidden
                            & _slenb                           // no one else is trying to sue the bus
                            & 
                            (
                             (
                              !_scs                            // our address in in lower half and we're in the selected slot.
                              & !data_base_or90[4]
                             )
                             | 
                             (
                              data_base_or90[4]                // or we're in the upper slot
                              & ce_ffxx                        // and we're in $ffxx
                              & 
                              (
                               address[7:5] == 3'b011          // they're asking for $ff6x or $ff7x
                              )
                             )
                            )
                            & 
                            (
                             address[4:1] == data_base_or90[3:0] // and top 3 bits of address are a match
                            )
                           ); // default to ff7a and ff7b
assign we_or90 =           ce_or90 & !r_w & e;
assign _channel[0] =       !(we_or90 & !address[0]);
assign _channel[1] =       !(we_or90 & address[0]);

assign baddress = 			{bank,address[11:0]};

assign ce_reg =            (
                            !flag_hidden                       // CocoFLASH is not hidden
                            & _slenb                           // no one is using the bus
                            & 
                            (                                
                             (
                              !_scs                            // we're in the lower half and we're in the selected slot
                              & !data_base[3]
                             ) 
                             | 
                             (
                              data_base[3]                     // or we're in the upper half
                              & ce_ffxx                        // and $ffxx is active
                              &
                              (
                               address[7:5] == 3'b011          // and they're asking for 6x or 7x
                              )
                             )
                            ) 
                            &
                            (
                             address[4:2] == data_base[2:0]    // and top 2 bits of address are a match
                            )
                           ); // b11111111 01 xxxx 00 - ff40-ff7c
assign we_reg =            !r_w & ce_reg;
assign we_reg_cmd = 			(we_reg & (address[1:0] == 0));
assign we_reg_bank_lo =    (we_reg & (address[1:0] == 1));
assign we_reg_bank_hi =    (we_reg & (address[1:0] == 2));
assign we_reg_spi = 	      (we_reg & (address[1:0] == 3));

assign we_reg_offset = 	   (!r_w & !ce_reg & !ce_or90 & !_scs & flag_offset);

assign data = 					(e & r_w & (!_cts | ce_reg | ce_or90) ? data_mux : 8'bz);
assign _oe = 					_cts;
assign _we = 					!(e & !r_w & address[15] & address[14] & !address[13] & flag_pgm); // you can write to c000-dfff  
assign _slenb =            (!_we |  we_reg_base ? 0 : 'bz);
assign bdata = 				(_we ? 8'bz : data);
assign _freset =           _reset;

assign bank[10:0] = 			data_bank[10:0] + {8'b0, address[14:12]} + {'b0, data_offset[7:0], 2'b0};
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

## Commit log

2018-02-21 General updates
    [CoCoFlash_v1.04c centroid.csv, CoCoFlash_v1.04c.brd, CoCoFlash_v1.04c.sch]
2019-05-21 Small PCB cleanup
    [CoCoFlash_v1.04c.brd, CoCoFlash_v1.04c.sch]

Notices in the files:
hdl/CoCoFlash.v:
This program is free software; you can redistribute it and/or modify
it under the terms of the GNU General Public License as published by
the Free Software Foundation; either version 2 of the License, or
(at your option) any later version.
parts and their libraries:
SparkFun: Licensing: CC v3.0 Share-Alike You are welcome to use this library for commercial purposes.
